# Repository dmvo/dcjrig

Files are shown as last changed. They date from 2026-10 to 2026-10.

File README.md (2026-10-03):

# DCJ11 test rig

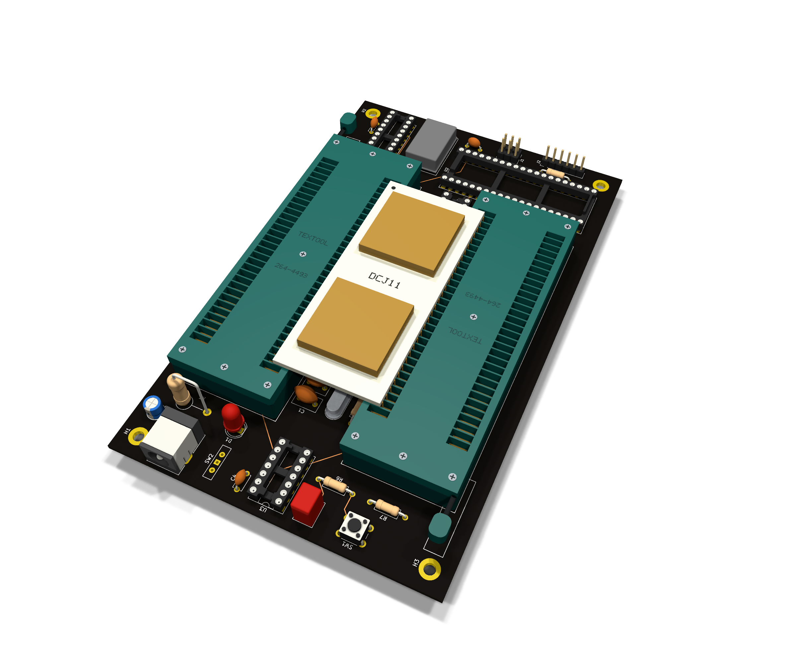
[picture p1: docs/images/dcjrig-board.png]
KiCad 3D render of the DCJ11 test rig


**A small KiCad project designed from scratch with AI assistance.**
The idea is to design without manual CAD work. The human gives instructions,
AI does the work, and the human checks the result. This covers the circuit,
custom parts, 3D models and documentation. For PCB routing, the human used
an autorouter.

[AGENTS.md](AGENTS.md) holds the rules we use to work this way.
You can copy it and adapt it for your own projects.

The rig gives a DEC DCJ11 processor a serial console for a quick check.
It uses a 4 MHz crystal, a DC319A DLART and two ZIF sockets.
The [GAL source and programming file](logic/gal/README.md) are included.
The board and GAL logic have not been tested on real hardware.

[Open in KiCad 10](kicad/rig/rig.kicad_pro) ·
[Build guide](docs/build.md) ·
[Sources and credits](THIRD_PARTY.md)

Inspired by Peter Schranz's
[Modular DCJ11 SBC](https://www.5volts.ch/pages/dcj11sbc/).

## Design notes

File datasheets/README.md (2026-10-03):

# Datasheets

The PDF files stay on the local machine and are ignored by Git.
These source notes tell you where to find them.

| Part | Source notes |
|---|---|
| DCJ11 | [Databook](DEC_DCJ11_1987_Databook.source.txt), [errata](DEC_Semiconductor_Databook_Vol1_1987_Errata.source.txt), [user guide](DEC_DCJ11_Users_Guide_Oct1983.source.txt) |
| DC319 and 74F821 | [DEC and National documents](DC319-and-74F821-sources.txt) |
| SN74AHCT14 | [TI Schmitt inverter](TI_SN74AHCT14.source.txt) |
| SN74AHCT541 | [TI bus buffer](TI_SN74AHCT541.source.txt) |
| GAL16V8 | [Lattice](Lattice_GAL16V8.source.txt) |
| VF154 oscillator | [Valpey-Fisher](Valpey-Fisher_VF150-series_VF154.source.txt) |
| HC-49S crystal case | [Elecsound](Elecsound_HC49S_Quartz_Crystal_Resonator.source.txt) |
| CPU package | [DEC dimensions](DEC_DCJ11_Mechanical_Dimensions_1987_E4.source.txt) |
| Textool sockets | [3M drawing](3M_Textool_264-4493_TS-0365.source.txt), [catalog](3M_Textool_Test_and_Burn-In_Socket_Catalog.source.txt) |
| Low DIP socket example | [3M 4800 series](3M_DIP_Socket_4800_TS1099.source.txt) |
| Power switch | [Wuerth](Wuerth_450301014042.source.txt) |

Save each PDF under the filename in its source note. KiCad uses these local
paths for its datasheet links. Some DEC files contain selected pages; their
notes give the page ranges. [SHA256SUMS.txt](SHA256SUMS.txt) identifies the
exact local copies.

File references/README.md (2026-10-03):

# Design inspiration and source files

Peter Schranz's [Modular DCJ11 SBC](https://www.5volts.ch/pages/dcj11sbc/)
inspired this rig. These links lead to his design and GAL source files.

- [Circuit description](https://www.5volts.ch/pages/dcj11sbc/060-dcj11-circuit-description/)
- [Hardware 1.3.3 download](https://www.5volts.ch/pages/dcj11sbc/downloads/Modular%20DCJ11-V1-3-3.zip)
- [GAL 1.3.2 download](https://www.5volts.ch/pages/dcj11sbc/downloads/DCJ11SBC-V1-3-2.zip)
- [GAL explanation](https://www.5volts.ch/pages/dcj11sbc/040-dcj11-gal-decoder/)
- [Using the console](https://www.5volts.ch/pages/dcj11sbc/070-dcj11-first-steps/)

The downloaded files stay local. [SHA256SUMS.txt](SHA256SUMS.txt) lists their
hashes. See [sources and credits](../THIRD_PARTY.md) for authorship and licenses.

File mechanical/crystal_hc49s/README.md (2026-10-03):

# HC-49S crystal

Y1 uses a low, through-hole 4 MHz crystal in an HC-49S case.
Its footprint is `DCJRig:Crystal_HC49S_Vertical`.

| Feature | Size |
|---|---:|
| Lead spacing | 4.88 mm |
| Drill diameter | 0.8 mm |
| Pad diameter | 2 mm |
| Body outline | 11.4 × 4.8 mm |
| Model height | 3.5 mm |
| Declared mounted height | 4.0 mm |

The 4 mm height allows a 0.5 mm gap under the body. Check the actual part
when fitting it. A crystal has no polarity.

The package dimensions follow the DIP drawing in
[Elecsound's HC49S sheet](../../datasheets/Elecsound_HC49S_Quartz_Crystal_Resonator.source.txt).
This is a size reference; it does not identify the maker of the stocked crystal.

To regenerate the 3D model:

```sh
python3 mechanical/crystal_hc49s/generate_model.py
```

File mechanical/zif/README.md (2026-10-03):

# Two ZIF sockets for one DCJ11

U1 uses two Textool 264-4493 sockets. Each has 64 contacts and a lever that
lets you insert the processor without forcing its pins.
The footprint is `DCJRig:DCJ11_DIP60_2xTextool_264-4493_ZIF`.

## Insert the CPU

Use the **two inner rows**, which are 33.02 mm apart. The CPU takes the
middle 30 contacts in each row. Leave **one empty contact at both ends**.
The outer rows stay unused.

The sockets face opposite ways. In the footprint's own orientation, one
lever is at the upper left and the other at the lower right. On the board,
follow the square pad and pin 1 mark. Turn power off before changing CPUs.

## Dimensions

| Feature | Size |
|---|---:|
| Pin pitch | 2.54 mm |
| CPU row spacing | 33.02 mm |
| Row spacing within each socket | 22.86 mm |
| Distance between socket centers | 55.88 mm |
| Socket body | 100.6 × 33.0 mm |
| Drill diameter | 1.1 mm |
| Copper pad | 3.2 × 1.9 mm |
| Clear width between the socket placement outlines | 21.88 mm |
| Maximum component height under the CPU | 11 mm |

All 128 socket leads have plated holes. Pads 1–60 connect to the CPU.
The other 68 pads are unnumbered and have no electrical connection.
[pad-map.csv](pad-map.csv) lists each hole and its CPU pin, where used.
The long pads leave room for hand soldering.

Dimensions come from the [3M socket drawing](../../datasheets/3M_Textool_264-4493_TS-0365.source.txt)
and [DEC package drawing](../../datasheets/DEC_DCJ11_Mechanical_Dimensions_1987_E4.source.txt).
Check the actual sockets against the [full-size template](assembly-1to1.pdf).
Print it at 100% and check its 50 mm scale with a ruler.

## Use the space under the CPU

Each socket has its own placement outline, called a courtyard in KiCad.
The gap between them is available for components.

Keep the complete mounted height below **11 mm**. This includes the IC,
its socket and any spacers. A 74F821 in a low DIP socket can fit: the
[3M example](../../datasheets/3M_DIP_Socket_4800_TS1099.source.txt) gives a
combined height of about 10.3 mm. Measure your own parts.

Set `Height_mm` on each component in the gap. Use its maximum assembled
height, not just the IC body height. Then run:

```sh
python3 mechanical/zif/check_height.py kicad/rig/rig.kicad_pcb
```

This needs KiCad 10's Python module. It checks the declared heights against
the area named `DCJ11_UNDER_CPU_H11`. A value above 11 mm fails. Missing
heights are reported as unknown. It does not measure the 3D models.

## Assembly and models

Fit low parts and DIP sockets before the large ZIF sockets. Solder the ZIF
sockets with their contacts **open**, as the
[3M catalog](../../datasheets/3M_Textool_Test_and_Burn-In_Socket_Catalog.source.txt)
instructs. Keep both bodies flat against the board while soldering.

The footprint has separate models for the sockets and CPU. Hide the CPU
model in KiCad's 3D settings to see the parts underneath. Small details such
as lever bends and contact jaws are approximate.

To regenerate the footprint, models, pin map and SVG drawing:

```sh
python3 mechanical/zif/generate.py
```

The generator uses Python's standard library. It writes library files;
it does not update the placed footprint on the board. Re-export
[assembly-1to1.svg](assembly-1to1.svg) to PDF if you change the drawing.

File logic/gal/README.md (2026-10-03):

# ODT bridge

The GAL16V8 at U6 connects the DCJ11 bus to the DC319A DLART and the
startup buffer. This directory contains everything needed to build and
program it, under the [MIT license](LICENSE).

**The logic has not been tested on real hardware.** The checks below prove
its Boolean behavior and check the programming file. They do not test
electrical timing or a working board.

- [odt_bridge.pld](odt_bridge.pld) — equations and pin assignments.
- [odt_bridge.jed](odt_bridge.jed) — programming file, built with galette 0.3.0.
- [design.md](design.md) — requirements, derivation and proof.
- [check_bridge.py](check_bridge.py) — independent source and fuse checks.

## Build on Linux

You need Python 3, Make and [galette](https://github.com/simon-frankau/galette).
To install the compiler with Rust and Cargo:

```sh
cargo install --git https://github.com/simon-frankau/galette \
  --rev af529870729b1da8794b002cd522f5bf2d53f230 --locked
```

From the project root, run:

```sh
make -C logic/gal check
```

This rebuilds `build/odt_bridge.jed`, checks it and the supplied file, then
compares them byte for byte. Each check covers all 512 board input
combinations. It also varies the tied input to prove the logic ignores it.

With KiCad 10 installed, also check the pin assignments against the saved
schematic:

```sh
make -C logic/gal check-wiring
```

This exports a netlist. It does not run ERC or change the schematic.

## Program with a T48

Use [minipro](https://gitlab.com/DavidGriffith/minipro) with T48 support
(version 0.7.4 is suitable). Select the device by the marking on your chip.
For a **GAL16V8D**, run from the project root:

```sh
python3 logic/gal/check_bridge.py
minipro -p GAL16V8D -w logic/gal/odt_bridge.jed
```

Minipro verifies after writing. Check that both steps succeed before
fitting U6. Programming verification does not mean the logic has been
tested in the rig.

DEC calls the serial chip a **DLART**: a DL11-compatible asynchronous
receiver/transmitter. The [DEC document](../../datasheets/DC319-and-74F821-sources.txt)
uses the full part name DC319-AA, on printed page 3-27.

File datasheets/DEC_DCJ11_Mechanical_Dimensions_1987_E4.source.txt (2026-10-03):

Publisher: Digital Equipment Corporation.
Document: Digital Semiconductor Databook, Volume 1, 1987, Appendix E.
Source: https://bitsavers.trailing-edge.com/pdf/dec/semiconductor/1987_Digital_Semiconductor_Databook_Vol_1.pdf
Local PDF: DEC_DCJ11_Mechanical_Dimensions_1987_E4.pdf

The local file is source PDF page 976, printed E-4. Use figure E.4 for DCJ11.
The page is marked Preliminary.

DCJ11 has 60 pins on a 0.100-inch pitch. The row spacing is 1.300 inches
(33.02 mm). Its nominal ceramic body is 3.000 × 1.288 inches.
Maximum body thickness: 0.211 inches.

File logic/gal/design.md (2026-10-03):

# ODT bridge: design and proof

**This logic has not been tested on real hardware.** This proof covers
steady Boolean levels. Propagation delays, startup transients and bus
timing still need checking on a built board.

The equations are written from this board's connections and the device
specifications below. Signal names beginning with `n` mean active LOW.
`AIO3:0`, `BS1:0` and `ADDR0` come from U4 and remain stable during a
transfer. `nBUF` and `nSCTL` come directly from the CPU.

## Sources

- DEC *Digital Semiconductor Databook*, Volume 1, 1987, DCJ11 chapter:
  Table 2 (transaction codes), Table 3 (bank codes), data control signals,
  and the read, write and GP-read cycle descriptions. Printed pages
  1-254–257 and 1-277–281.
  [Source and local filename](../../datasheets/DEC_DCJ11_1987_Databook.source.txt).
- DEC DC319-AA: pin functions on page 3-29 and bus timing in Figure 7
  and Table 9 on page 3-39. Its corrected first page identifies it as
  a DLART. [Source notes](../../datasheets/DC319-and-74F821-sources.txt).
- Lattice GAL16V8, May 2001: simple mode and fuse layout, pages 8–9.
  [Source notes](../../datasheets/Lattice_GAL16V8.source.txt).

## Pin assignments

| U6 pin | Source name | Connection |
|---|---|---|
| 1–4 | AIO3, AIO2, AIO1, AIO0 | U4 latched transaction code |
| 5, 6 | BS0, BS1 | U4 latched bank code |
| 7 | nSCTL | CPU /SCTL |
| 8 | nBUF | CPU /BUFCTL; also U5 enable pin 1 |
| 9 | ADDR0 | Latched address bit 0; also DLART A0 |
| 10, 20 | GND, VCC | Supply |
| 11 | NC | Board holds this input HIGH; equations do not use it |
| 12 | nREAD | DLART /RD, via net /OE |
| 15 | nWRITE | DLART /WLB, via net /WEL |
| 18 | nSELECT | DLART /CS, via net /IO |
| 19 | nBOOT | U5 enable pin 19, via net /GPREAD |
| 13, 14, 16, 17 | PARK13, PARK14, PARK16, PARK17 | Unconnected; outputs held LOW |

The CPU's /MISS and /CONT inputs connect directly to GND. The GAL does
not drive them. This selects stretched reads and adds no external wait.

## Required behavior

Let `a` be the four-bit transaction code, `b` the two-bit bank code,
`q = ADDR0`, `u = nBUF`, and `s = nSCTL`. The numbers below are hexadecimal.

| Output is LOW exactly when… | Meaning |
|---|---|
| `b = 2` | Select the external-I/O bank |
| `a ∈ {8,9,A,B,C}` and `u = 0` | Read during the CPU's released-bus interval |
| `a ∈ {0,1,2,3}`, `q = 0`, and `s = 0` | Write a DLART low byte at an even address |
| `a = E` | Select the startup buffer for a GP read |

The DLART requires both /CS and the appropriate read or write control.
The startup buffer requires both its enables LOW. Thus its actual bus
enable also requires `u = 0`.

There is one device in the external-I/O bank. The board decodes only the
bank and address bits 2:0, so the DLART registers repeat every eight bytes
within that bank. The fixed startup word serves GP reads; the board has
no floating-point unit or other GP-read device.

## Derivation

Use `¬` for NOT, `∧` for AND and `∨` for OR. Write the transaction bits
as `a3…a0`, and bank bits as `b1,b0`. Define the active conditions:

```text
select = b1 ∧ ¬b0
read   = ¬u ∧ a3 ∧ (¬a2 ∨ (¬a1 ∧ ¬a0))
write  = ¬a3 ∧ ¬a2 ∧ ¬q ∧ ¬s
boot   = a3 ∧ a2 ∧ a1 ∧ ¬a0
```

Each physical output is the complement of its active condition.

1. `b1 ∧ ¬b0` is true only for bank code `10`, DEC's external-I/O bank.
2. For reads, `a3 ∧ ¬a2` selects codes `8…B`. The remaining product
   `a3 ∧ ¬a1 ∧ ¬a0` selects `8` and `C`. Their union is exactly
   `{8,9,A,B,C}`. Multiplying by `¬u` limits reads to a released DAL bus.
3. `¬a3 ∧ ¬a2` selects exactly codes `0…3`: bus word and byte writes.
   The DLART writes its low byte only with A0 LOW. `¬q` supplies that
   condition; `¬s` supplies the stretched write phase.
4. All four bits in `boot` are specified, so it selects only code `E`.

Distributing the read expression gives the two product terms in the
source. The other expressions each need one. These cover every input
combination; no undefined cases are used to simplify the equations.

The read and write code sets are disjoint. GP read is also outside both
sets. Therefore read and write cannot overlap, and the DLART and startup
buffer cannot drive the bus together at steady inputs. Both read paths
require `u = 0`, so neither is enabled while the CPU drives DAL.

## Check the programming file

`check_bridge.py` builds its expected results from numeric code sets.
It separately evaluates the source and the JEDEC fuse array for all
`16 × 4 × 2 × 2 × 2 = 512` combinations. Repeating with pin 11 LOW and
HIGH gives 1024 cases and proves that this input has no effect.

The fuse decoder follows Lattice's simple-mode layout:

- Fuses 0–2047 are 64 product rows, each 32 columns wide.
- Row-enable fuses start at 2128. A connected signal and its complement
  make a row false. Otherwise, connected literals are ANDed.
- Eight rows feed each output, in pin order 19 down to 12.
- Polarity fuses 2048–2055 select the physical output level.
- Fuses 2192 and 2193 must be `1,0`; fuses 2120–2127 must all be zero.
  This gives always-enabled combinatorial outputs without registers.

The checker rejects feedback, checks both JEDEC checksums, and verifies
the source pin order. `make check-wiring` also checks the saved schematic's
control connections and the CPU's grounded inputs.

These checks establish the specified Boolean behavior of the equations
and programming data. They do not establish that the complete rig works.

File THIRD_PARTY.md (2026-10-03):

# Sources and credits

## Design inspiration

The circuit was inspired by Peter Schranz's
[Modular DCJ11 SBC](https://www.5volts.ch/pages/dcj11sbc/).
His hardware and GAL downloads credit **Peter Schranz / cbscpe** and
**Netzwerk & Design GmbH**. Those archives stay local.
[Reference links](references/README.md) point to his site and downloads.

## GAL logic

[ODT bridge](logic/gal/README.md) is written for this board from its wiring
and the DEC and Lattice device specifications. Its source, programming file,
build scripts and explanation are included under the
[MIT license](logic/gal/LICENSE). The [design notes](logic/gal/design.md)
show how the equations follow from those specifications.

The logic has not been tested on real hardware.

## KiCad libraries

The design uses parts from the KiCad library contributors.
`DCJRig:SN74AHCT14N` adapts KiCad's `74xx:74HC14` symbol for the stocked TI part.
Its name, description, keywords and datasheet link are different.

The KiCad parts and their adaptations keep **CC BY-SA 4.0 with the KiCad
design exception**. See the [upstream notice](licenses/KiCad-libraries-LICENSE.md),
[license text](https://creativecommons.org/licenses/by-sa/4.0/legalcode) and
[KiCad's explanation](https://www.kicad.org/libraries/license/).
The exception covers use in circuit designs; sharing library collections has
separate requirements. The source library is
[kicad-symbols](https://gitlab.com/kicad/libraries/kicad-symbols).

The CPU, UART and latch symbols were drawn for this project. So were the
socket and crystal footprints and their 3D models. Their Python generators
are included under `mechanical/`.

## Datasheets

We don't publish datasheets because we don't know what licenses cover them.
We provide [download links](datasheets/README.md) and
[SHA256 checksums](datasheets/SHA256SUMS.txt) so you can get the documents
we use and check that you have the same copies.
The socket assembly PDF under `mechanical/` is our own drawing.

## Reusing project files

You may copy and adapt [AGENTS.md](AGENTS.md) for your own projects.
The files in `logic/gal/` use MIT. No license has been chosen for the other
original project files.
The third-party licenses above still apply to their respective parts.

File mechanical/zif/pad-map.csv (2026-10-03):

socket | row | station_from_lever | x_mm | y_mm | cpu_pin
L | outer | 1 | -39.3700 | -39.3700
L | outer | 2 | -39.3700 | -36.8300
L | outer | 3 | -39.3700 | -34.2900
L | outer | 4 | -39.3700 | -31.7500
L | outer | 5 | -39.3700 | -29.2100
L | outer | 6 | -39.3700 | -26.6700
L | outer | 7 | -39.3700 | -24.1300
L | outer | 8 | -39.3700 | -21.5900
L | outer | 9 | -39.3700 | -19.0500
L | outer | 10 | -39.3700 | -16.5100
L | outer | 11 | -39.3700 | -13.9700
L | outer | 12 | -39.3700 | -11.4300
L | outer | 13 | -39.3700 | -8.8900
L | outer | 14 | -39.3700 | -6.3500
L | outer | 15 | -39.3700 | -3.8100
L | outer | 16 | -39.3700 | -1.2700
L | outer | 17 | -39.3700 | 1.2700
L | outer | 18 | -39.3700 | 3.8100
L | outer | 19 | -39.3700 | 6.3500
L | outer | 20 | -39.3700 | 8.8900
L | outer | 21 | -39.3700 | 11.4300
L | outer | 22 | -39.3700 | 13.9700
L | outer | 23 | -39.3700 | 16.5100
L | outer | 24 | -39.3700 | 19.0500
L | outer | 25 | -39.3700 | 21.5900
L | outer | 26 | -39.3700 | 24.1300
L | outer | 27 | -39.3700 | 26.6700
L | outer | 28 | -39.3700 | 29.2100
L | outer | 29 | -39.3700 | 31.7500
L | outer | 30 | -39.3700 | 34.2900
L | outer | 31 | -39.3700 | 36.8300
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

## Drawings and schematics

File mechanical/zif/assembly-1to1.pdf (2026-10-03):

## DCJ11 / 2 x TEXTOOL 264-4493

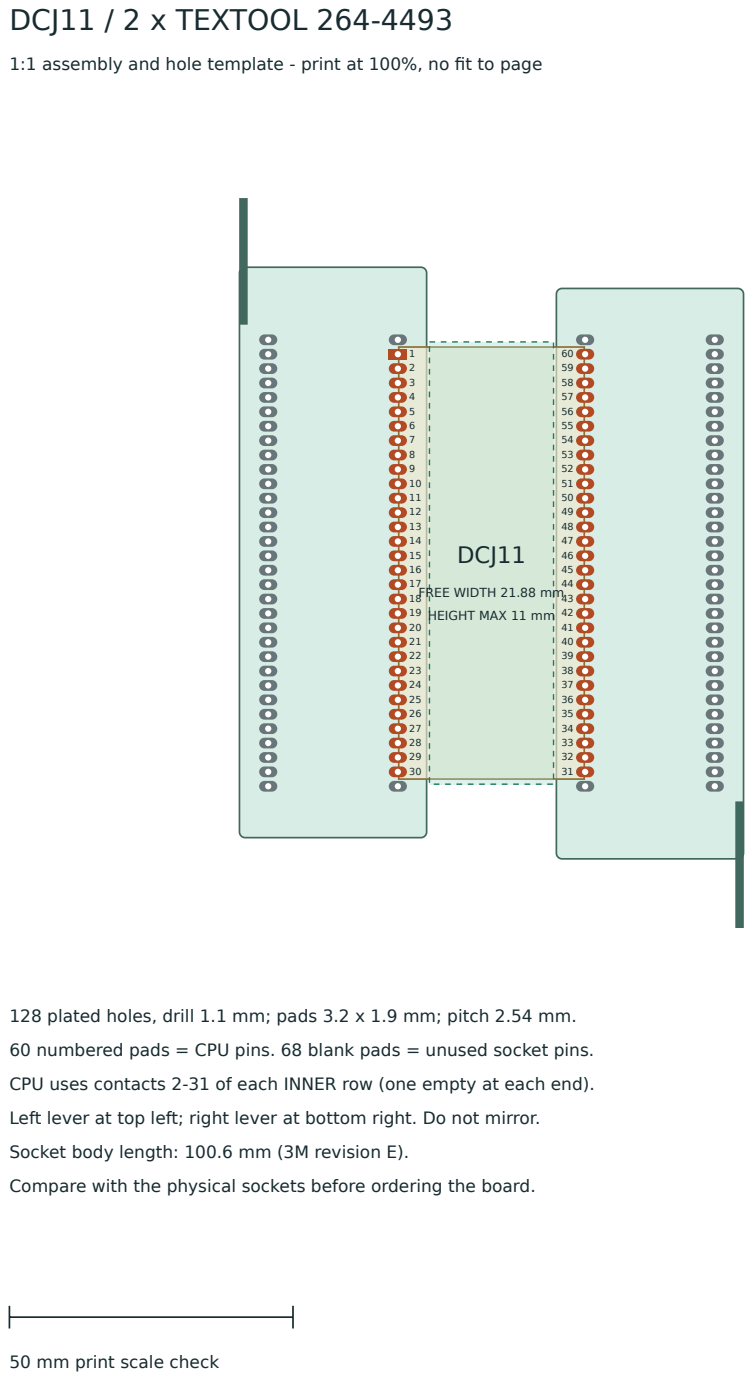
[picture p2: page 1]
DCJ11; FREE WIDTH 21.88 mm; HEIGHT MAX 11 mm

1:1 assembly and hole template - print at 100%, no fit to page

128 plated holes, drill 1.1 mm; pads 3.2 x 1.9 mm; pitch 2.54 mm.
60 numbered pads = CPU pins. 68 blank pads = unused socket pins.
CPU uses contacts 2-31 of each INNER row (one empty at each end).
Left lever at top left; right lever at bottom right. Do not mirror.
Socket body length: 100.6 mm (3M revision E).
Compare with the physical sockets before ordering the board.

50 mm print scale check

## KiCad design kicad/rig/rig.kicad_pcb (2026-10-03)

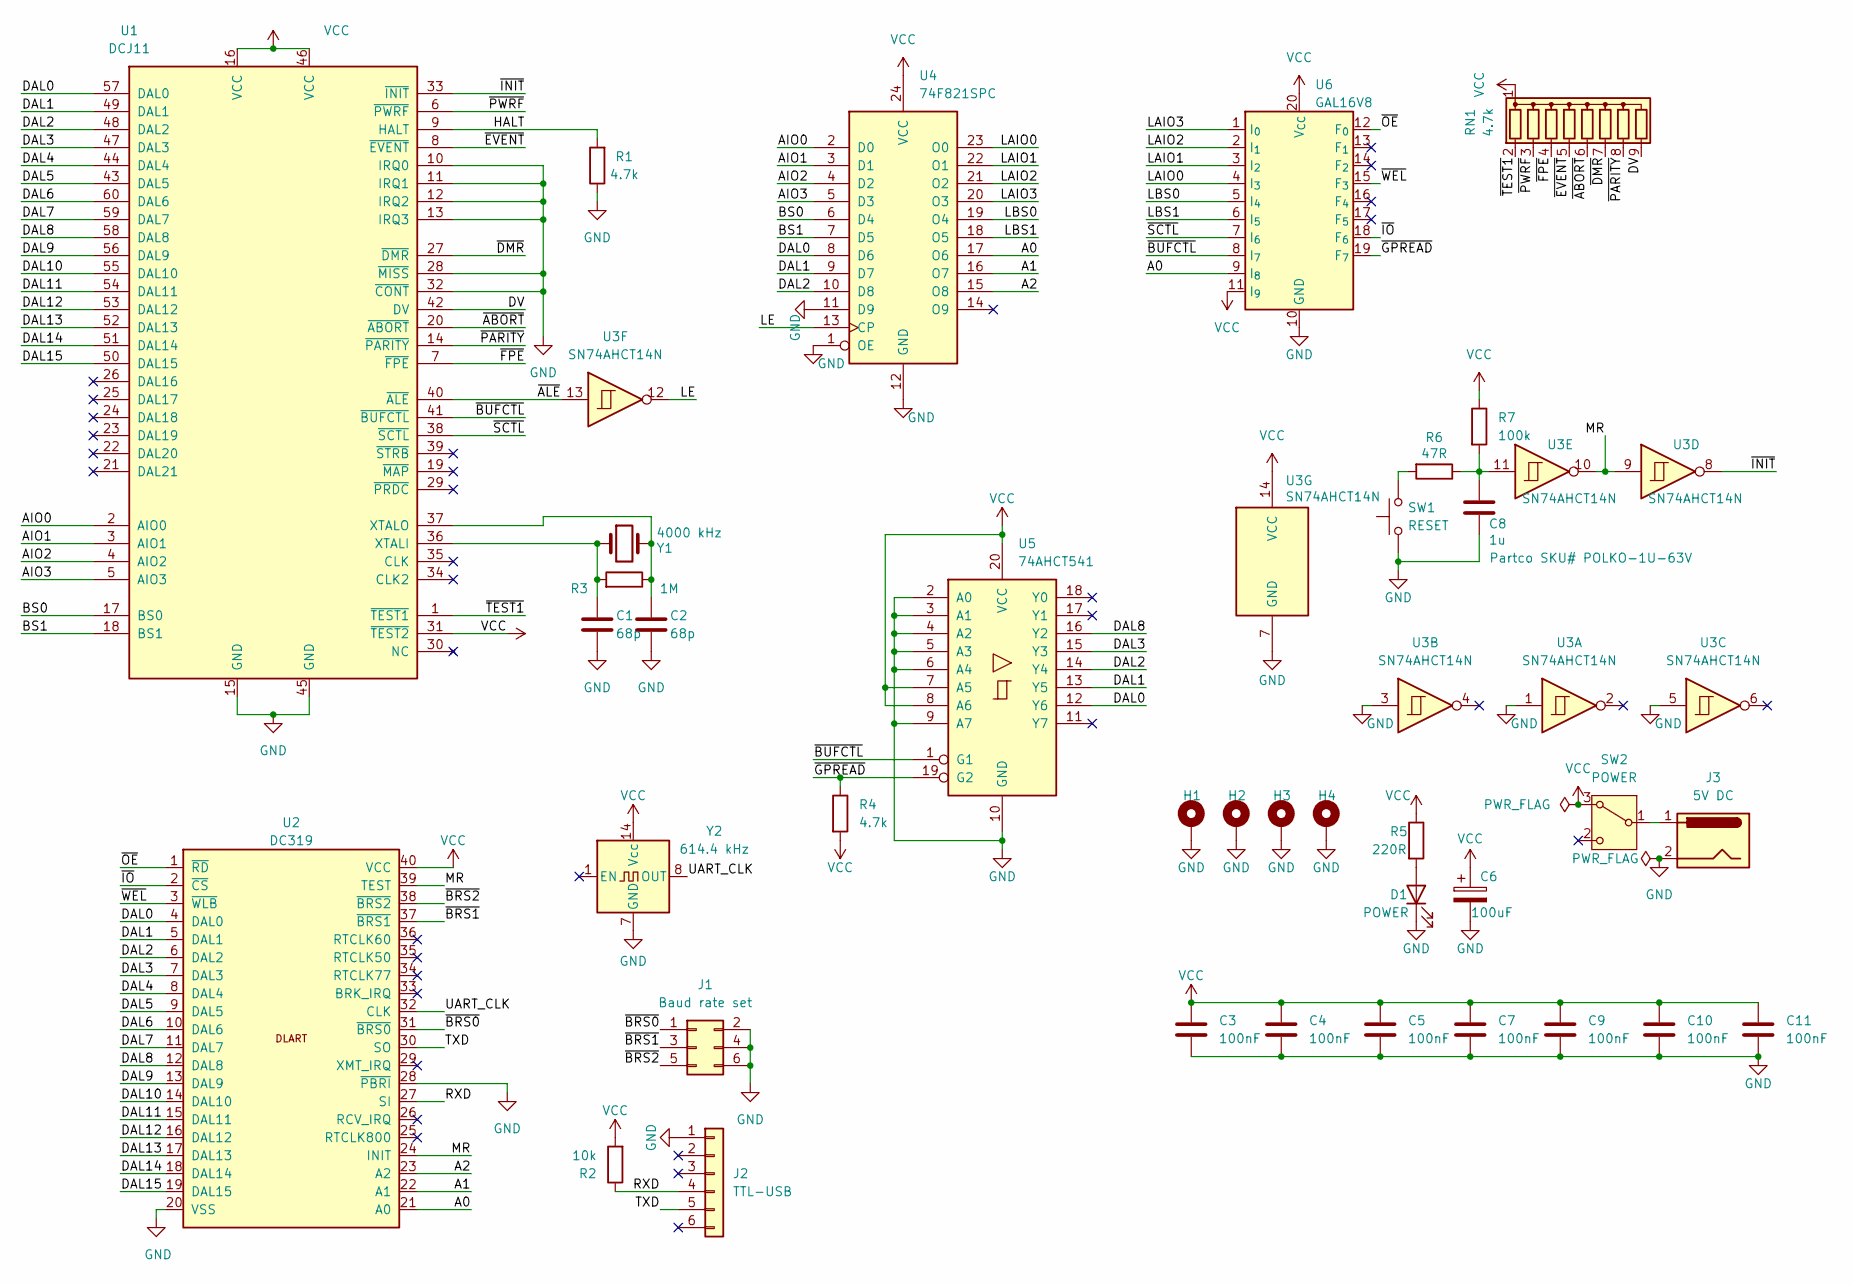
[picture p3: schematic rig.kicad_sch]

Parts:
C1, C2: 68p; C_Disc_D7.5mm_W4.4mm_P5.00mm
C3, C4, C5, C7, C9, C10, C11: 100nF; C_Disc_D4.7mm_W2.5mm_P5.00mm
C6: 100uF; CP_Radial_D5.0mm_P2.00mm
C8: 1u; C_Rect_L7.2mm_W5.5mm_P5.00mm_FKS2_FKP2_MKS2_MKP2; Partco Partco SKU# POLKO-1U-63V
D1: POWER; LED_D5.0mm
H1, H2, H3, H4: MountingHole_Pad; MountingHole_3.2mm_M3_DIN965_Pad
J1: Baud rate set; PinHeader_2x03_P2.54mm_Vertical
J2: TTL-USB; PinHeader_1x06_P2.54mm_Vertical
J3: 5V DC; BarrelJack_CUI_PJ-063AH_Horizontal
R1, R4: 4.7k; R_Axial_DIN0207_L6.3mm_D2.5mm_P10.16mm_Horizontal
R2: 10k; R_Axial_DIN0207_L6.3mm_D2.5mm_P10.16mm_Horizontal
R3: 1M; R_Axial_DIN0207_L6.3mm_D2.5mm_P10.16mm_Horizontal
R5: 220R; R_Axial_DIN0414_L11.9mm_D4.5mm_P7.62mm_Vertical
R6: 47R; R_Axial_DIN0207_L6.3mm_D2.5mm_P10.16mm_Horizontal
R7: 100k; R_Axial_DIN0207_L6.3mm_D2.5mm_P10.16mm_Horizontal
RN1: 4.7k; R_Array_SIP9
SW1: RESET; SW_PUSH_6mm
SW2: POWER; SW_Slide-03_Wuerth-WS-SLTV_10x2.5x6.4_P2.54mm
U1: DCJ11; DCJ11_DIP60_2xTextool_264-4493_ZIF
U2: DC319; DIP-40_W15.24mm_Socket_LongPads
U3: SN74AHCT14N; DIP-14_W7.62mm_Socket_LongPads
U4: 74F821SPC; DIP-24_W7.62mm_Socket_LongPads
U5: 74AHCT541; DIP-20_W7.62mm_Socket_LongPads
U6: GAL16V8; DIP-20_W7.62mm_Socket_LongPads
Y1: 4000 kHz; Crystal_HC49S_Vertical
Y2: 614.4 kHz; Oscillator_DIP-14

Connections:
/A0: U2.21 (A0), U4.17 (O6), U6.9 (I_{8})
/A1: U2.22 (A1), U4.16 (O7)
/A2: U2.23 (A2), U4.15 (O8)
/AIO0: U1.2 (AIO0), U4.2 (D0)
/AIO1: U1.3 (AIO1), U4.3 (D1)
/AIO2: U1.4 (AIO2), U4.4 (D2)
/AIO3: U1.5 (AIO3), U4.5 (D3)
/BS0: U1.17 (BS0), U4.6 (D4)
/BS1: U1.18 (BS1), U4.7 (D5)
/DAL0: U1.57 (DAL0), U2.4 (DAL0), U4.8 (D6), U5.12 (Y6)
/DAL1: U1.49 (DAL1), U2.5 (DAL1), U4.9 (D7), U5.13 (Y5)
/DAL2: U1.48 (DAL2), U2.6 (DAL2), U4.10 (D8), U5.14 (Y4)
/DAL3: U1.47 (DAL3), U2.7 (DAL3), U5.15 (Y3)
/DAL4: U1.44 (DAL4), U2.8 (DAL4)
/DAL5: U1.43 (DAL5), U2.9 (DAL5)
/DAL6: U1.60 (DAL6), U2.10 (DAL6)
/DAL7: U1.59 (DAL7), U2.11 (DAL7)
/DAL8: U1.58 (DAL8), U2.12 (DAL8), U5.16 (Y2)
/DAL9: U1.56 (DAL9), U2.13 (DAL9)
/DAL10: U1.55 (DAL10), U2.14 (DAL10)
/DAL11: U1.54 (DAL11), U2.15 (DAL11)
/DAL12: U1.53 (DAL12), U2.16 (DAL12)
/DAL13: U1.52 (DAL13), U2.17 (DAL13)
/DAL14: U1.51 (DAL14), U2.18 (DAL14)
/DAL15: U1.50 (DAL15), U2.19 (DAL15)
/DV: RN1.9 (R8), U1.42 (DV)
/HALT: R1.2, U1.9 (HALT)
/LAIO0: U4.23 (O0), U6.4 (I_{3})
/LAIO1: U4.22 (O1), U6.3 (I_{2})
/LAIO2: U4.21 (O2), U6.2 (I_{1})
/LAIO3: U4.20 (O3), U6.1 (I_{0})
/LBS0: U4.19 (O4), U6.5 (I_{4})
/LBS1: U4.18 (O5), U6.6 (I_{5})
/LE: U3.12, U4.13 (CP)
/MR: U2.24 (INIT), U2.39 (TEST), U3.9, U3.10
/RXD: J2.4, R2.1, U2.27 (SI)
/TXD: J2.5, U2.30 (SO)
/UART_CLK: U2.32 (CLK), Y2.8 (OUT)
/~ABORT: RN1.6 (R5), U1.20 (~ABORT)
/~ALE: U1.40 (~ALE), U3.13
/~BRS0: J1.1, U2.31 (~BRS0)
/~BRS1: J1.3, U2.37 (~BRS1)
/~BRS2: J1.5, U2.38 (~BRS2)
/~BUFCTL: U1.41 (~BUFCTL), U5.1 (G1), U6.8 (I_{7})
/~DMR: RN1.7 (R6), U1.27 (~DMR)
/~EVENT: RN1.5 (R4), U1.8 (~EVENT)
/~FPE: RN1.4 (R3), U1.7 (~FPE)
/~GPREAD: R4.1, U5.19 (G2), U6.19 (F_{7})
/~INIT: U1.33 (~INIT), U3.8
/~IO: U2.2 (~CS), U6.18 (F_{6})
/~OE: U2.1 (~RD), U6.12 (F_{0})
/~PARITY: RN1.8 (R7), U1.14 (~PARITY)
/~PWRF: RN1.3 (R2), U1.6 (~PWRF)
/~SCTL: U1.38 (~SCTL), U6.7 (I_{6})
/~TEST1: RN1.2 (R1), U1.1 (~TEST1)
/~WEL: U2.3 (~WLB), U6.15 (F_{3})
GND: C1.2, C2.2, C3.2, C4.2, C5.2, C6.2, C7.2, C8.2, C9.2, C10.2, C11.2, D1.1 (K), H1.1 (1_1), H2.1 (1_1), H3.1 (1_1), H4.1 (1_1), J1.2, J1.4, J1.6, J2.1, J3.2, R1.1, SW1.1, U1.10 (IRQ0), U1.11 (IRQ1), U1.12 (IRQ2), U1.13 (IRQ3), U1.15 (GND), U1.28 (~MISS), U1.32 (~CONT), U1.45 (GND), U2.20 (VSS), U2.28 (~PBRI), U3.1, U3.3, U3.5, U3.7 (GND), U4.1 (OE), U4.11 (D9), U4.12 (GND), U5.2 (A0), U5.3 (A1), U5.4 (A2), U5.5 (A3), U5.6 (A4), U5.9 (A7), U5.10 (GND), U6.10 (GND), Y2.7 (GND)
unnamed: C8.1, R6.1, R7.2, U3.11
unnamed: D1.2 (A), R5.2
unnamed: R6.2, SW1.2
unnamed: J3.1, SW2.1 (B)
unnamed: C1.1, R3.2, U1.36 (XTALI), Y1.1
unnamed: C2.1, R3.1, U1.37 (XTALO), Y1.2
VCC: C3.1, C4.1, C5.1, C6.1, C7.1, C9.1, C10.1, C11.1, R2.2, R4.2, R5.1, R7.1, RN1.1 (common), SW2.3 (A), U1.16 (VCC), U1.31 (~TEST2), U1.46 (VCC), U2.40 (VCC), U3.14 (VCC), U4.24 (VCC), U5.7 (A5), U5.8 (A6), U5.20 (VCC), U6.11 (I_{9}), U6.20 (V_{CC}), Y2.14 (Vcc)

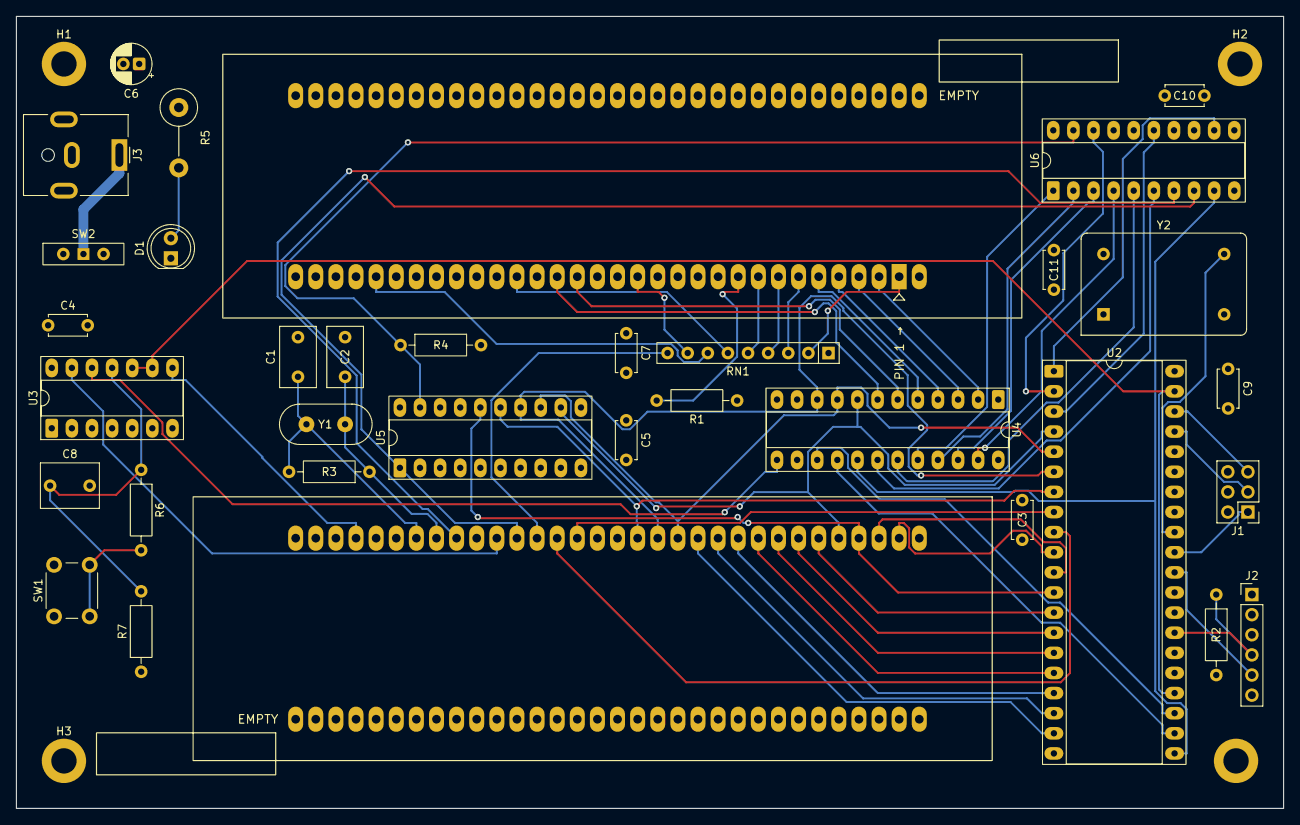
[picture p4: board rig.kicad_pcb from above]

Board: 4 copper layers, 160.0 x 100.0 mm, 37 parts (0 on the bottom side), 64 nets.

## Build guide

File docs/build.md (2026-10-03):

# Build guide

## What the board does

The rig lets a DEC DCJ11-AE processor talk to a serial terminal through its
built-in ODT console. This gives you a quick way to check whether the CPU
starts and responds. It does not test every CPU function.

| Part | Job |
|---|---|
| U1 — DCJ11-AE | Processor under test |
| U2 — DC319A DLART | Serial interface |
| U3 — SN74AHCT14N | Reset and clock-signal inversion |
| U4 — 74F821SPC | Holds address and control bits during a bus cycle |
| U5 — 74AHCT541 | Supplies the startup settings for ODT |
| U6 — GAL16V8 | Selects the UART and controls bus transfers |
| Y1 — 4 MHz HC-49S crystal | CPU clock |
| Y2 — VF154, 614.4 kHz | UART clock |

The board is 160 × 100 mm, with four copper layers and a 1.6 mm thickness.
The outer layers carry signals. The inner layers carry ground and 5 V.

## Open the design

Open `kicad/rig/rig.kicad_pro` in KiCad 10. The project includes its custom
symbols, footprints and 3D models. Install KiCad's standard libraries too.

The picture in the main README is a render of this board in KiCad. Some
library models show empty IC sockets, and the slide switch has no model.
Run `bash docs/render.sh` to make the picture again.

## Fit the processor

The two Textool 264-4493 sockets hold the CPU in their **inner rows**.
Use the middle 30 contacts of each row. Leave one contact empty at each end.
Follow the board's pin 1 mark. Turn power off before inserting or removing
the processor.

Parts under the CPU must be **no more than 11 mm above the PCB**. Include
sockets and any gap below the component in that measurement. Check the
assembled height of U4 and U5 before inserting the CPU.

The [socket guide](../mechanical/zif/README.md) has dimensions, a printable
template and a height checker. The [crystal guide](../mechanical/crystal_hc49s/README.md)
describes the low HC-49S case.

## Connect power and a terminal

Use an external, regulated **5 V** supply at J3. Its center contact is positive.
SW2 switches power; SW1 resets the rig. J2 carries serial signals, not power.

Use a USB-to-TTL serial adapter with levels suitable for the 5 V DC319.
Connect these three pins:

| Rig connector | Adapter |
|---|---|
| J2 pin 1 — GND | GND |
| J2 pin 4 — RX | TX |
| J2 pin 5 — TX | RX |

Leave J2 pins 2, 3 and 6 unconnected. This is a TTL interface; do not connect
an RS-232 port directly.

For **9600 baud, 8N1**, close J1 pairs **1–2 and 5–6**. Leave 3–4 open.
The startup settings are wired for ODT entry.

## GAL programming

U6 needs a programmed GAL. The [GAL guide](../logic/gal/README.md) includes
the source, a programming file and instructions for galette and minipro
on Linux. The logic has not been tested on real hardware.

## Before relying on a result

The design has not yet been tested on a built board. First check the rig
with a known-good CPU. A silent console alone is not enough to reject a CPU.
A useful quick test includes both the ODT prompt and a response to a command.

Two timing details still need checking on the hardware: startup data must
stay valid long enough after its buffer turns off, and the CPU's data-valid
input is held HIGH. The render also cannot confirm real component heights.

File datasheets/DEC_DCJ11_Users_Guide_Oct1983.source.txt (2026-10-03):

Publisher: Digital Equipment Corporation.
Document: EK-DCJ11-UG-PRE, DCJ11 Microprocessor User's Guide.
Edition: October 1983, preliminary.
Source: https://dusted.dk/pages/computers/J-11/datasheet-DEC-DCJ11_Microprocessor_Users_Guide_OCR.pdf
Local PDF: DEC_DCJ11_Users_Guide_Oct1983.pdf

Covers the bus, startup, ODT and processor control signals.
Use the production databook and its errata for electrical limits.

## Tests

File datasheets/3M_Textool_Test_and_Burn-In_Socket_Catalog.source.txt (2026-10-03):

Manufacturer: 3M
Document: Textool Test and Burn-In Socket Catalog.
Source: https://multimedia.3m.com/mws/media/351660O/3m-tm-textool-tm-test-and-burn-in-socket-catalog.pdf
Local PDF: 3M_Textool_Test_and_Burn-In_Socket_Catalog.pdf

Printed page 16 lists the 264-4493 socket.
Printed page 1 gives the installation instructions: solder with contacts open.

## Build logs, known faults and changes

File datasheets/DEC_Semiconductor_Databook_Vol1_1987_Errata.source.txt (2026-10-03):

Publisher: Digital Equipment Corporation.
Document: Digital Semiconductor Databook, Volume 1, 1987, Errata.
Source: https://bitsavers.trailing-edge.com/pdf/dec/semiconductor/1987_Digital_Semiconductor_Databook_Vol_1_Errata.pdf
Local PDF: DEC_Semiconductor_Databook_Vol1_1987_Errata.pdf

Includes corrected DCJ11 electrical and timing tables.
Use these corrections when reading the databook.

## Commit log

2026-10-03 hardware: add custom symbols, footprints and mechanical models
    [pad-map.csv]
2026-10-03 hardware: import the current DCJ11 rig schematic and routed board
    [rig.kicad_pcb, rig.kicad_sch]
2026-10-03 docs: add the build guide and a render of the board
2026-10-14 Update KiCad rig for GAL20V8A and late DV capture
    Add the GAL20V8A-15LP symbol and complete the matching schematic and routing. Keep separate read and write test points, widen the input power trace to 1.1 mm, and update bypass capacitor placement.
    Checked physical pin connectivity, startup bits, current GAL20V8 working-tree logic, and conditional bus timing. PCB DRC and schematic parity pass. Hardware operation remains untested.
2026-10-14 Build and verify minimal GAL20V8A ODT bridge logic
    Match the DIP24 board pinout, park unused outputs, and independently verify source equations and JEDEC fuses for all 16384 input combinations. Prove the minimum of five product terms and 17 literals.
    Include Linux build and T48 programming instructions, timing assumptions, and source references. The logic has not been tested on hardware.
2026-10-14 Enlarge ZIF holes for measured socket pins and refill board
2026-10-14 Move test point labels to back silkscreen
2026-10-14 Widen ZIF pads and clear GPREAD routing around socket end
2026-10-14 Record fabrication package for the JLCPCB order
    The JLCPCB board order will use this exact ZIP archive:
    dcjrig-jlcpcb-3ac8660.zip
    Source design: 3ac86600964d7aee4f46b01ecc0059f89fc56a84
    Archive SHA-256:
    5eb298b77ce7f579e2de078b05f036bcf09e61c55b88a3ee9de4ed4ff8a60af7
    Order settings: 4-layer FR-4, 160 x 100 mm, 1.6 mm board thickness,
    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
2026-10-14 Refresh public docs and render the current board
    Replace the stale README image with a KiCad render of the saved board. Link the fabrication package and document its layer order and copper weight.
    Clarify exact parts, GAL checks, socket measurements, PDF excerpt hashes, and missing height data. Remove obsolete GAL16V8 references, repair source links, and fix overlapping labels in the full-size socket template.
    Each document stays within its previous word and character count; total text is 293 words shorter. Checked local links, source hashes, GAL build and fresh schematic netlist. Hardware design, logic binaries, and the order ZIP are unchanged.
2026-10-25 Publish component checks and assembled-board documentation
    Add repeatable T48 test generators and selected unchanged measurements.
    Verify all GAL input combinations and its fuse readback; retain the unresolved
    DC319 clock-output result and distinguish chip tests from board operation.
    Document the assembled, unpowered board, 38400-baud setup and wired power jack.
    Add masked assembly photos with unchanged board pixels on a separate page.
    Keep session archives, repeated logs and personal machine details local.
2026-11-08 Add ODT CPU test suite and record five passing CPUs
    The rig has no memory, so the suite checks a DCJ11 through console ODT
    only: general registers in both sets, PC, stack pointers, PSW, all 96
    MMU registers, MMR0/MMR3, PIRQ, CCR, and the DLART bus path. A negative
    control and a reset check complete the run for each CPU.
    Five DCJ11 CPUs passed in the assembled rig at 38400 baud. Link the suite
    and its result from the README, build guide, assembly notes, GAL notes
    and component checks.
